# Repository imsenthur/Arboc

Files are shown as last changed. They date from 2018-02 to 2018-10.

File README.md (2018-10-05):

# Arboc
# Abstract:

Researches about underwater propulsion mainly illustrate the use of propellers or thrusters to propel a robot in an underwater environment whereas most of the aquatic animals change their body shape in order to navigate.The shape-change generating propulsion force makes them move forward or backward effectively.The underwater snake-like robot is a kind of bionic robot which changes its body shape to navigate in underwater environment.The aim of the project is to understand the dynamics of underwater robots in general and the effect of lift, drag and hydrodynamic coefficients on them and to simulate, validate and develop a snake-like robot which is robust enough to carry out underwater exploratory tasks.

# Scope of research ::

  •	Comprehensive simulation and validation of underwater bionic robots using ROS and gazebo.

  •	Goal based locomotion and object tracking for underwater exploratory robots using deep reinforcement learning.
  
# Team:

  • Aditya Singh [https://github.com/adityasingh3007]
  
  • Bhavya Krishna [https://github.com/BhavyaKrishna]
  
  • DC Vivek [https://github.com/dc28vivek]
  
  • Jack Samuel S [https://github.com/jaxxstar] 
  
  • Manu Aatitya [https://github.com/manuaatitya]  
  
  • Senthur Raj [https://github.com/imsenthur]
  
  • Vibashan VS [https://github.com/Vibashan]

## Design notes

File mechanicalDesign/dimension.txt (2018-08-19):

Head:
	Ixx=0.00021427111 kg*m2
	Iyy=0.00021427111 kg*m2
	Izz=0.000054 kg*m2
	rad=0.0335 m
	length=0.0765 m
	mass=0.095875 kg
Module:
	Ixx=0.0001378755 kg*m2
	Iyy=0.0001378755 kg*m2
	Izz=0.000052 kg*m2
	rad=0.0335 m
	length=0.06 m
	mass=0.093195 kg
Tail:
	Ixx=0.00064931795 kg*m2
	Iyy=0.00064931795 kg*m2
	Izz=0.000074 kg*m2
	rad=33.50mm
	length=118mm
	mass=0.13195 kg

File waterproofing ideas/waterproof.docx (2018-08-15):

Prebuilt waterproof:

Bang good waterproof servo = 972.43 (6.8k for 7)

Waterproofing manually (quite durable):

Method 1:

Materials reqd. :

Marine grease (730 Rs. For 7)

Plasti dip(900 Rs. For 7) (amazon)

Procedure:

Use marine grease on the top side of the servo where the gear is present, ehich does not allow water to flow from the top side of the servo.

Then use plasti dip to coat the servo with the plastic material which acts like a shrink tape when it dries and makes it really waterproof

During the plasti dip process we need to be careful to remove any air pockets near the edges during the drying phase and also make sure that the servo rotates in the drying phase

Once the plasti dip dries it looks like that there is an layer of plastic coat all over the servo which looks really sturdy

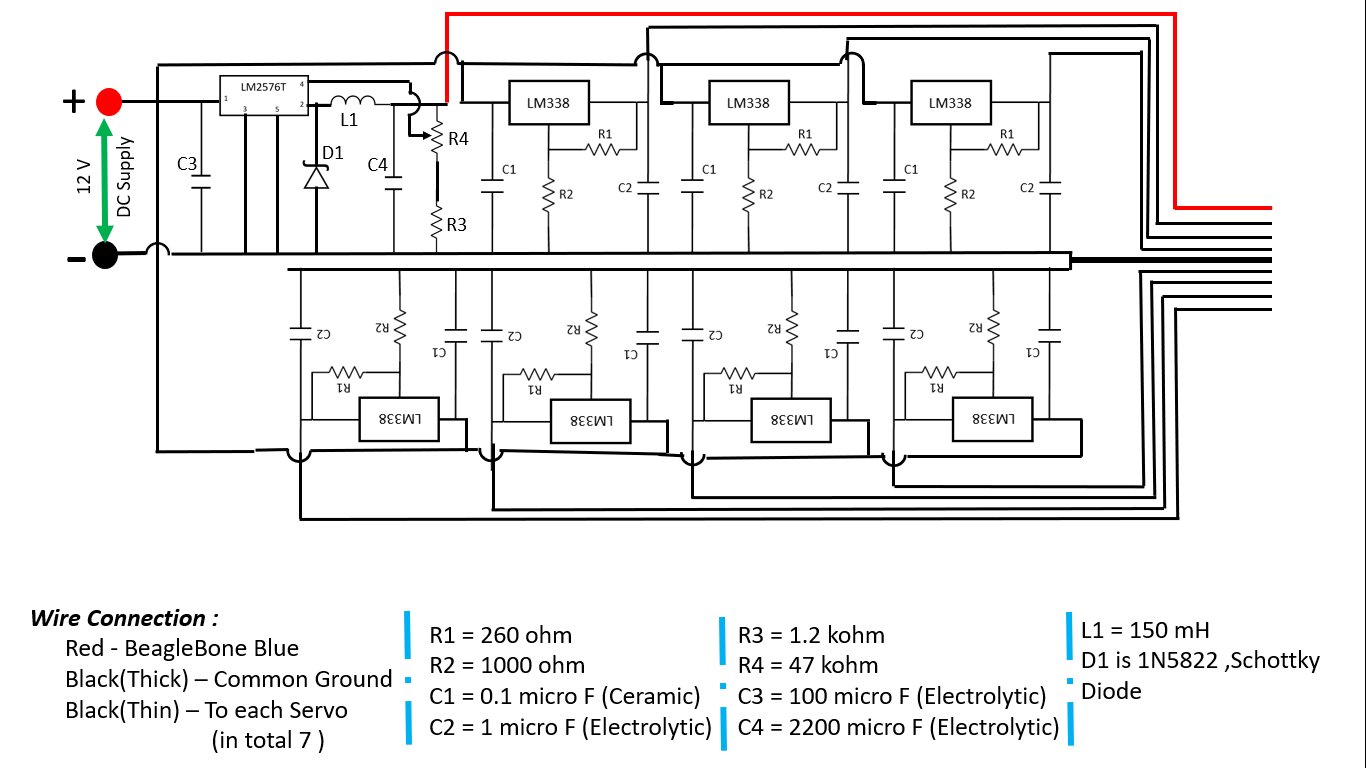
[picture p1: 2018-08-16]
powerSupplyDesign/circuit.png

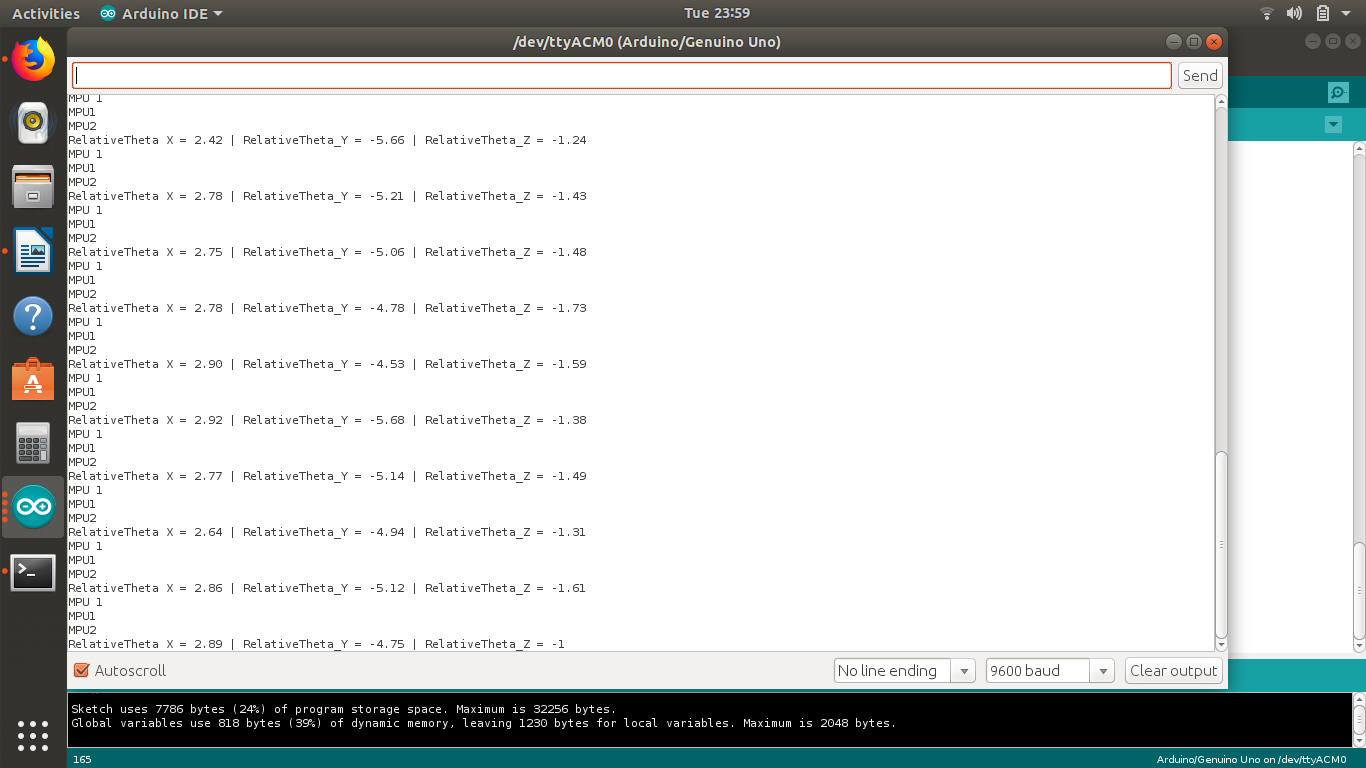
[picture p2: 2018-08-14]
control/IMU/Relative_angle.png

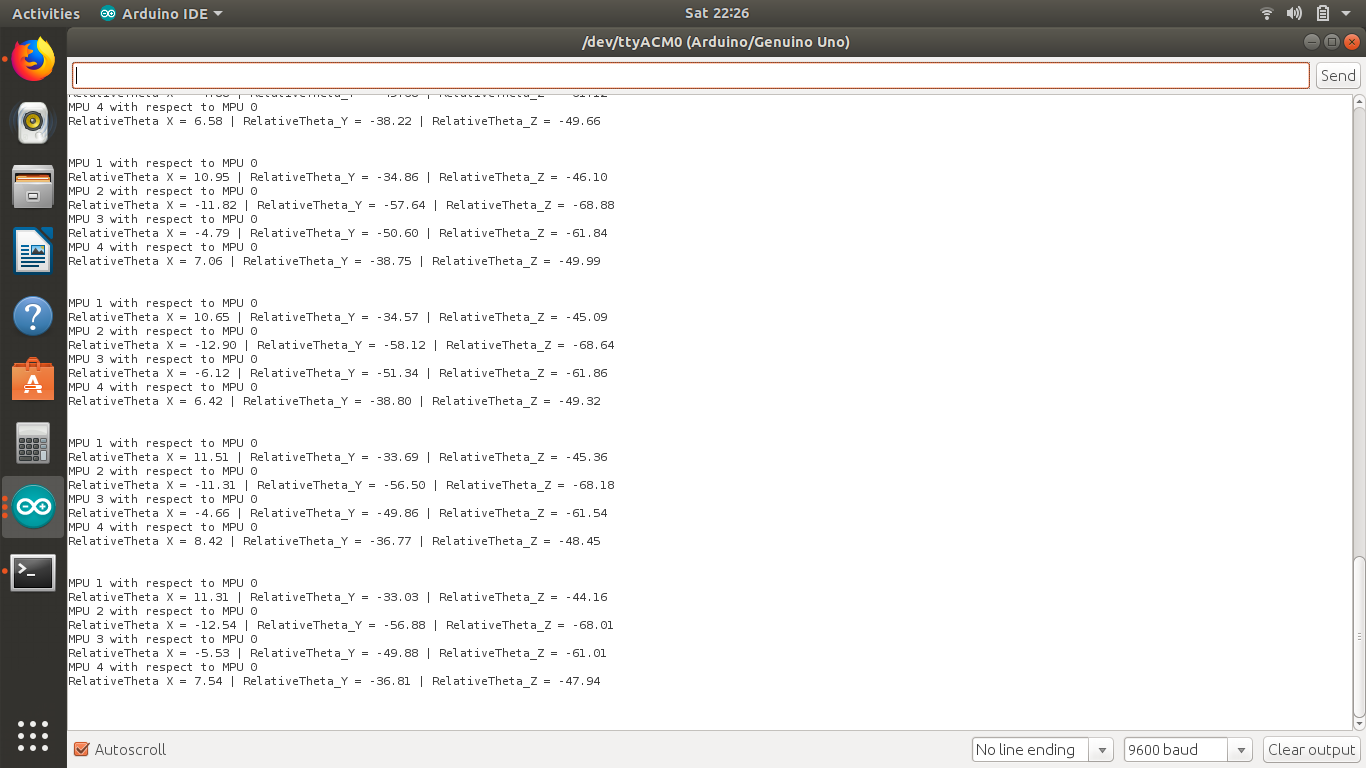
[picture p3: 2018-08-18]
control/IMU/relative_angle_5imu.png

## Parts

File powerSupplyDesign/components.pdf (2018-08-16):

LIST OF CIRCUIT ELEMENTS

S No. | Name | Range / Value | Qty
1. | LM338T Voltage Regulator (TO-220) | 1.2V to 32V, 5A | 10
2. | LM2576T Adj Regulator (TO-220) | | 03
3. | Resistor | 220 ohm,¼ watt 1 kohm,¼ watt 1.2 kohm,¼ watt | 10 10 03
4. | Rheostat | 47 kohm,¼ watt | 02
5. | Capacitor (Electrolytic) | 1 uF, 20 V 100 uF, 30 V 2200 uF, 20 V | 10 03 03
6. | Capacitor (Ceramic) | 0.1 uF, 30V | 10
7. | Inductor (CD74R) | 150 mH | 03
8. | Schottky Diode (1N5822) | 10-20V | 03
9. | Heat sinks | 1k/watt thermal resistance 30Watts disspation capacity | 10
10 | Thermal grease

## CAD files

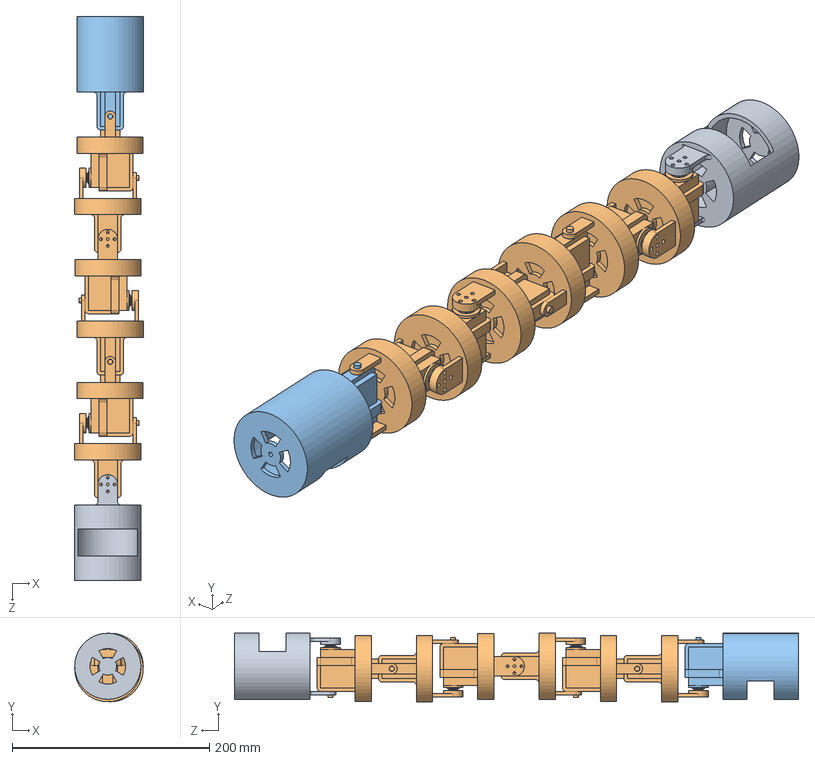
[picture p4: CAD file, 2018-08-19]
mechanicalDesign/solidworks/mainAssembly/arboc.SLDASM
69.5 x 69.5 x 571.3 mm
head
module x 6
tail

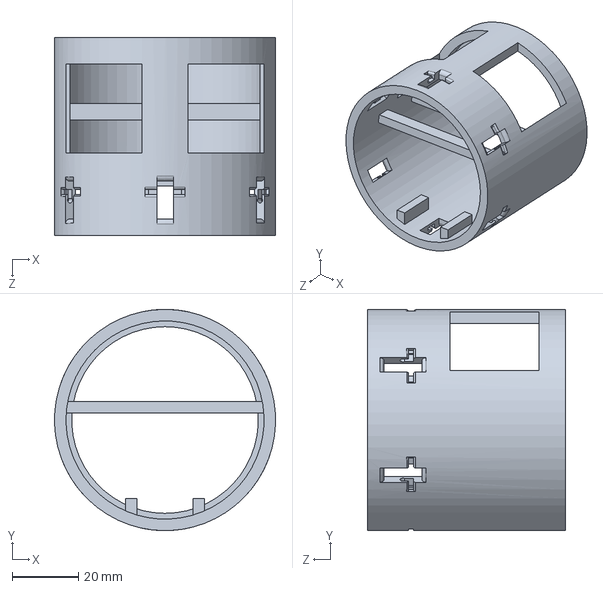
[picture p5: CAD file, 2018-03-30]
mechanicalDesign/solidworks/subAssembly/headNew.SLDASM
66.9 x 67.0 x 60.0 mm

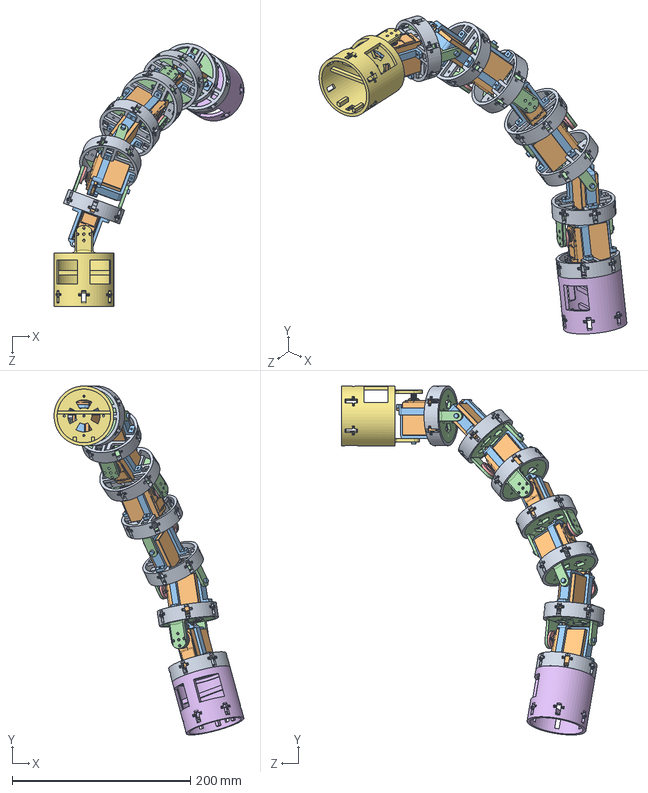
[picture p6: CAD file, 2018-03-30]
mechanicalDesign/solidworks/mainAssembly/arbocImprov.SLDASM
212.8 x 391.1 x 294.4 mm
LowerBracket x 7
Servo x 7
MiddleBracket x 7
UpperBracket x 6
Metalhorn x 6
Tail
Newhead

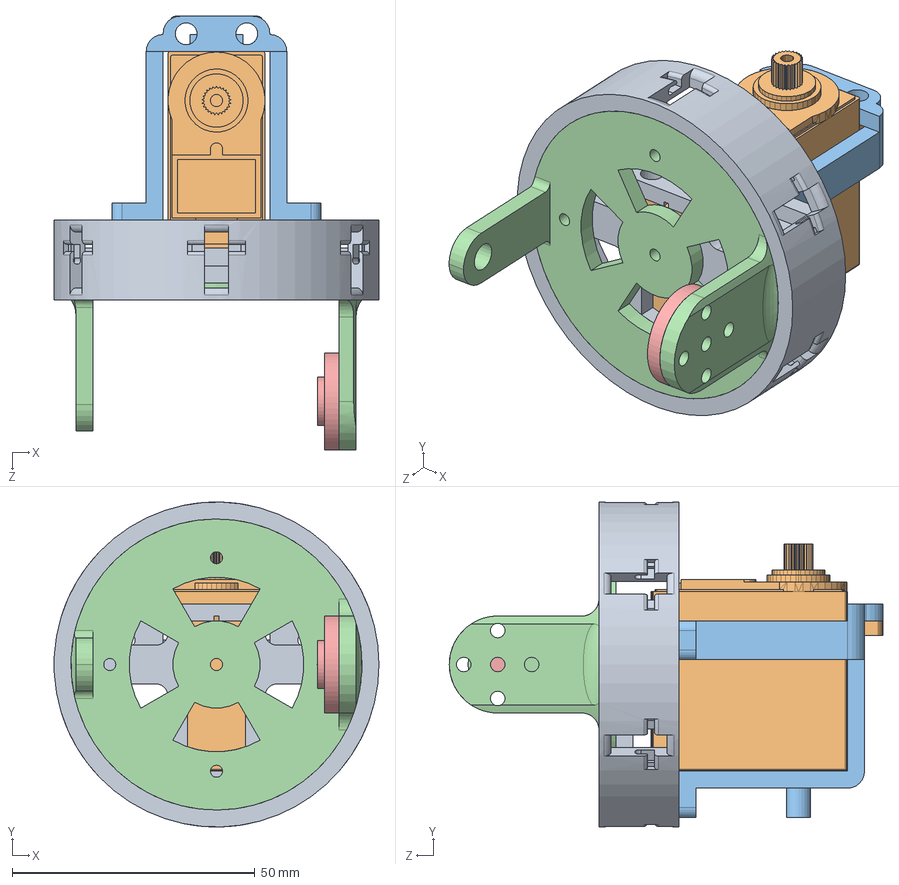
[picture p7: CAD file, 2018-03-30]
mechanicalDesign/solidworks/subAssembly/module.SLDASM
67.0 x 67.0 x 89.4 mm
LowerBracket
Servo
MiddleBracket
UpperBracket
Metalhorn

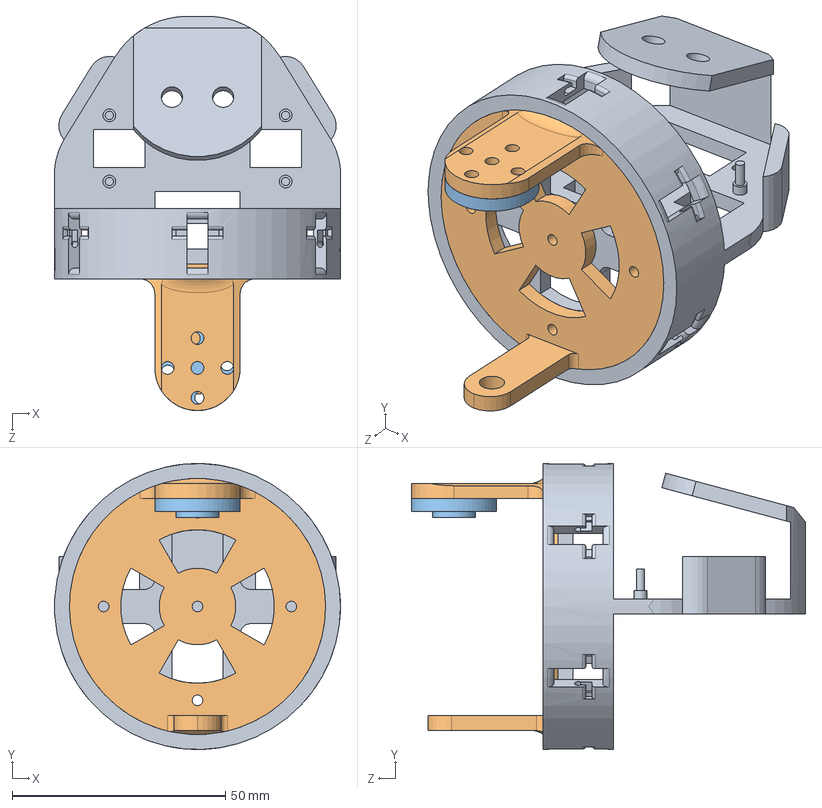
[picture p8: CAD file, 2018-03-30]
mechanicalDesign/solidworks/subAssembly/head.SLDASM
67.0 x 67.0 x 92.4 mm
Head
UpperBracket
Metalhorn

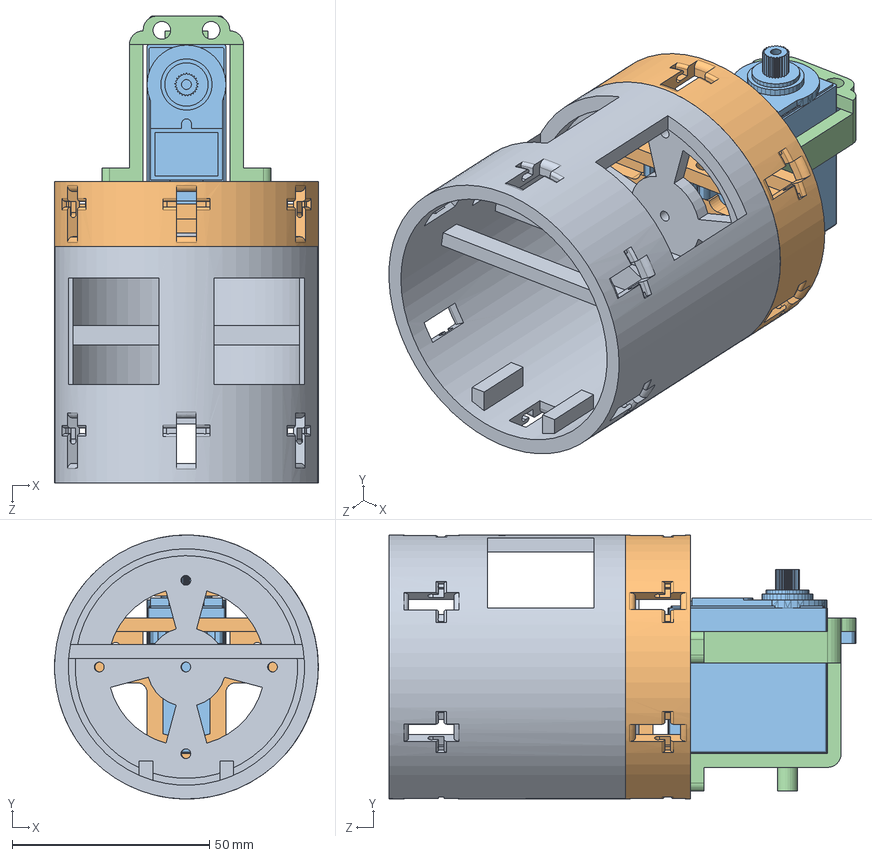
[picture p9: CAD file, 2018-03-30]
mechanicalDesign/solidworks/subAssembly/tail.SLDASM
67.0 x 67.0 x 118.5 mm
Tail
LowerBracket
Servo
MiddleBracket

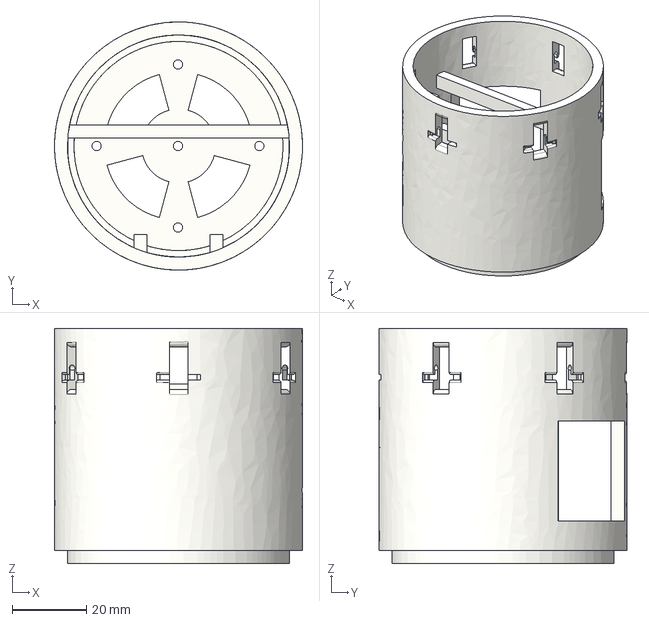
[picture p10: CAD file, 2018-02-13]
mechanicalDesign/3DprintedParts/type5.step
66.9 x 67.0 x 63.5 mm

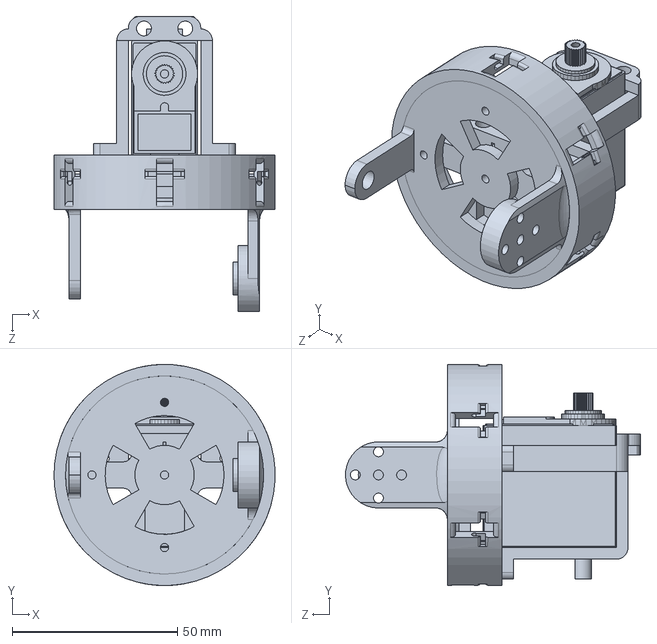
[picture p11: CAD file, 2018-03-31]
mechanicalDesign/solidworks/iges/link.SLDPRT
67.0 x 67.0 x 89.4 mm

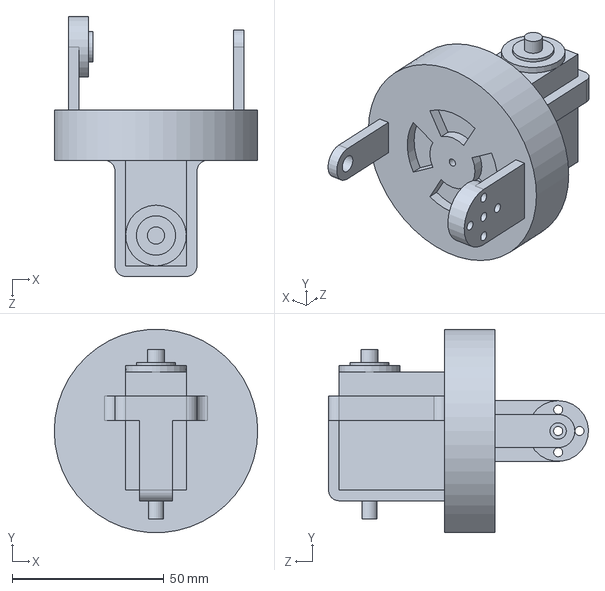
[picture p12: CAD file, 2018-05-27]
mechanicalDesign/solidworks/sldprt/module.SLDPRT
67.0 x 66.8 x 85.6 mm

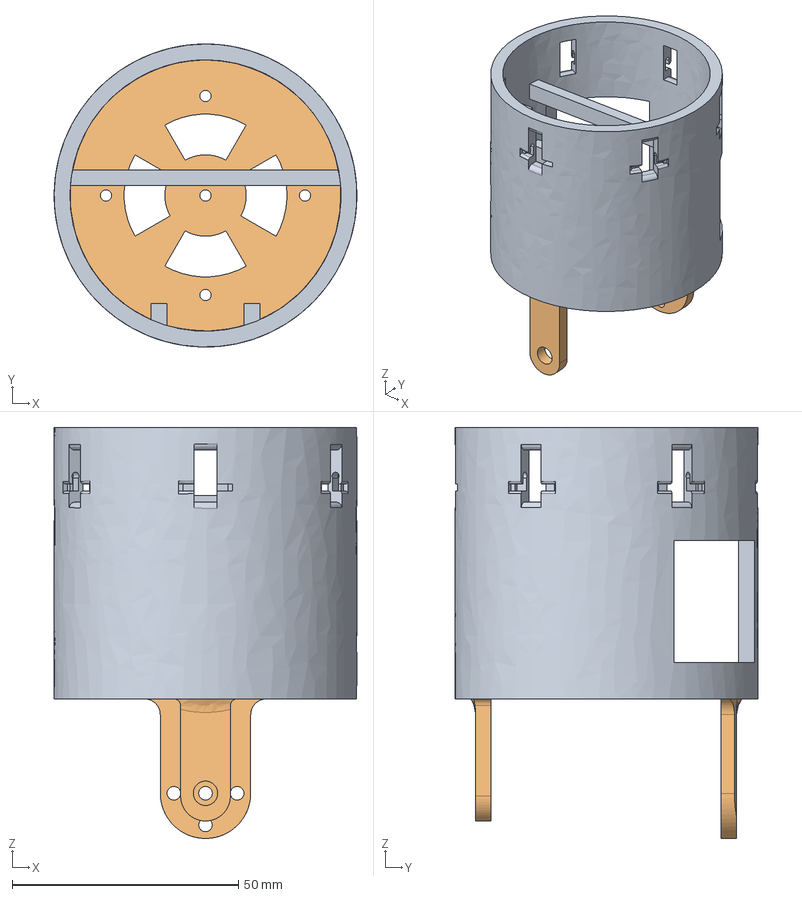
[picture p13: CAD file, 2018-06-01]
mechanicalDesign/solidworks/step/newHead.step
66.9 x 67.0 x 90.9 mm
Tail v1
UpperBracket v1

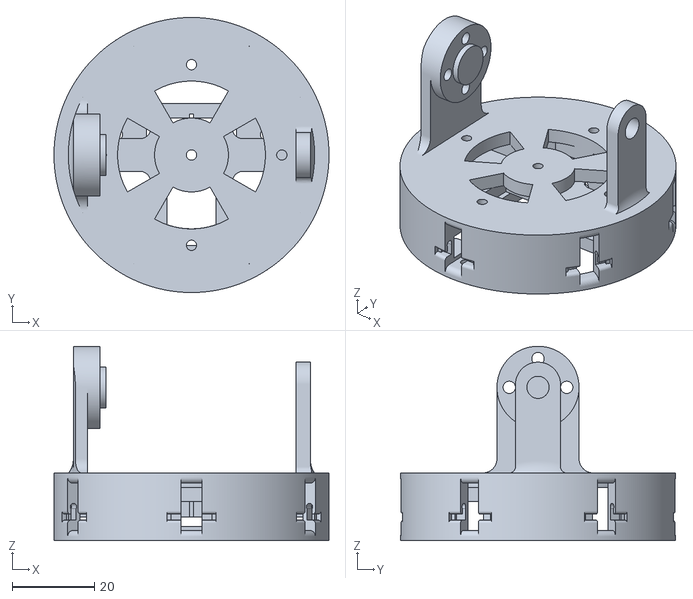
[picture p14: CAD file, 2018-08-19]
simulationExports/gazebo/stl/topModule.stl
67.0 x 67.0 x 47.4

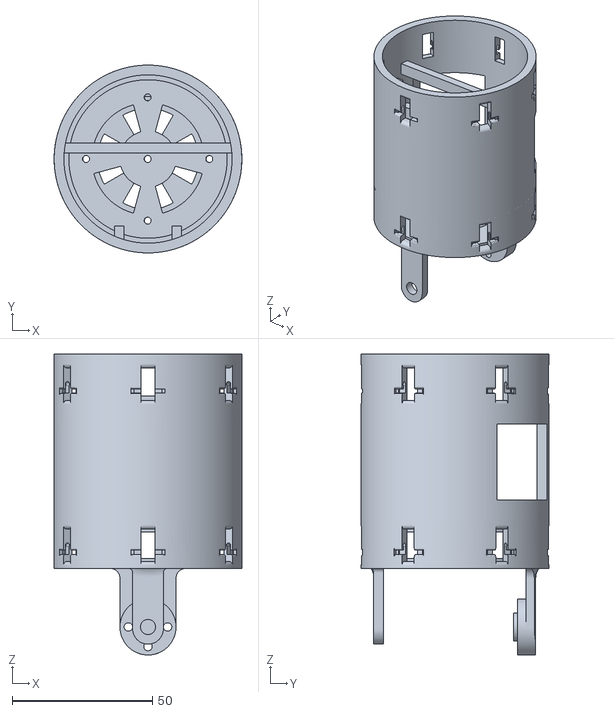
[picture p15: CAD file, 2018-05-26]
simulationExports/vrep/stl/headVisible.stl
67.0 x 67.0 x 107.4

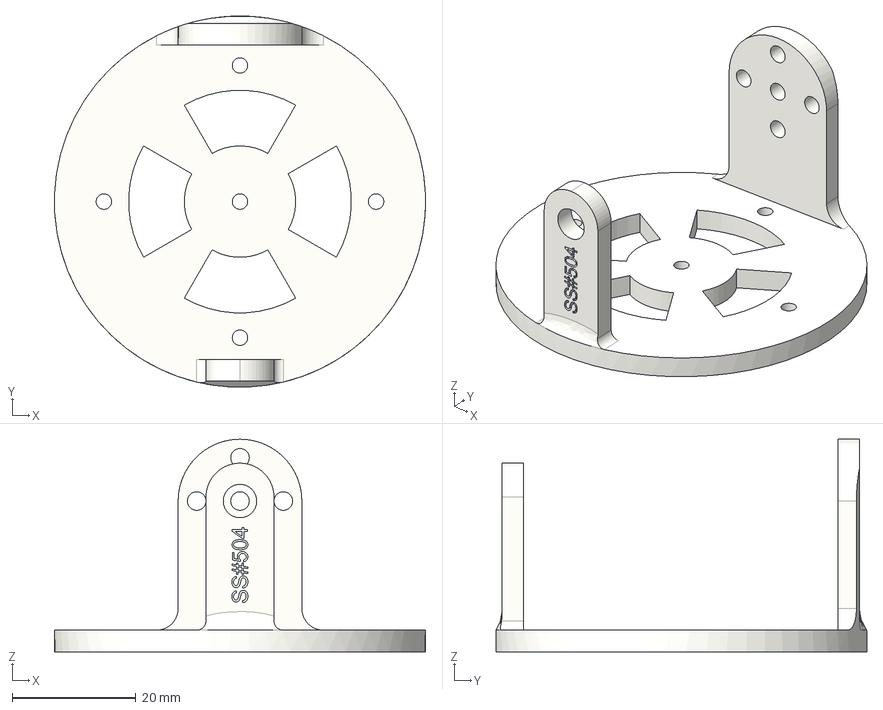
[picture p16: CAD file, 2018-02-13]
mechanicalDesign/3DprintedParts/type3.step
60.0 x 60.0 x 34.4 mm

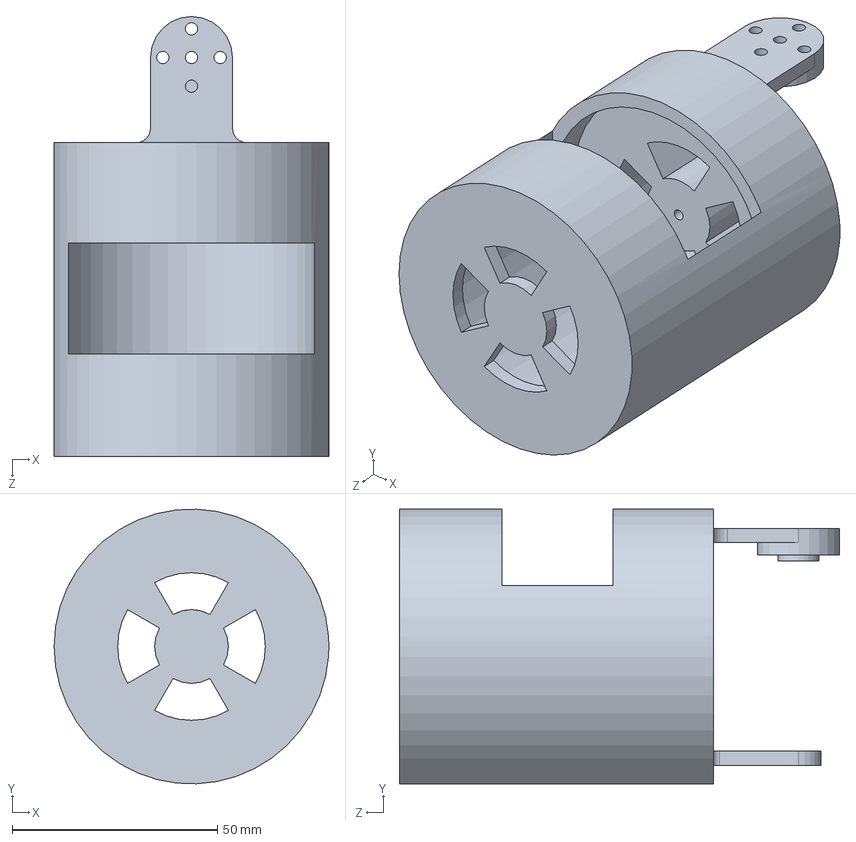
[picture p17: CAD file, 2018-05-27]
mechanicalDesign/solidworks/sldprt/head.SLDPRT
67.0 x 67.0 x 107.3 mm

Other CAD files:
mechanicalDesign/solidworks/iges/headLink.SLDPRT
mechanicalDesign/solidworks/step/metalHorn.step
simulationExports/gazebo/stl/moduleLeft.stl
simulationExports/vrep/stl/tailVisible.stl
mechanicalDesign/3DprintedParts/type1.step
mechanicalDesign/3DprintedParts/type1.stl
mechanicalDesign/3DprintedParts/type2.step
mechanicalDesign/3DprintedParts/type2.stl
mechanicalDesign/3DprintedParts/type3.stl
mechanicalDesign/3DprintedParts/type4.step
mechanicalDesign/3DprintedParts/type4.stl
mechanicalDesign/3DprintedParts/type5.stl
mechanicalDesign/3DprintedParts/type6.step
mechanicalDesign/3DprintedParts/type6.stl
mechanicalDesign/fusion360/NewDesignexport.f3d
mechanicalDesign/solidworks/iges/tailLink.SLDPRT
mechanicalDesign/solidworks/sldprt/headMod.SLDPRT
mechanicalDesign/solidworks/sldprt/headNew.SLDPRT
mechanicalDesign/solidworks/sldprt/lowerBracket.SLDPRT
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

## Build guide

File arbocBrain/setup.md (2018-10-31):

# arbocBrain

>  With an aim of tasking the robot with gait generation and goal based locomotion, we have buffed up a Beaglebone Blue with numerous packages that aid in both server-client communication and client-side computation.

## Installation

BeagleBone® Blue is an all-in-one Linux-based computer for robotics which comes preloaded with a Debian distribution (Debian jessie) which can be upgraded to a latest firmware from https://beagleboard.org/latest-images. Since most of the computation and processing is done with ROS on the server, it becomes crucial that the client has an active installation of ROS with all the necessary packages. Though ROS distros are available for Debian, its a bit finicky when it comes to installation and support. So we flashed the Beaglebone Blue with a custom ubuntu image (ubuntu 16.04) which we found at https://jh.app.box.com/v/530-707-Dropbox, which is a pre-built image courtesy of Robert Nelson, Jeff O’Brian, and louis whitcomb that comes with ROS Kinetic pre-installed. The entire process has been explained further with much detail below.

#### Expanding file system partition:
The image mentioned above is a 8GB ubuntu-16.04 image which converts the attached SD card to a file system of 8GB capacity irrespective of its native capacity. Make sure to expand the file system partition before proceeding further.

Refer to https://dev.iachieved.it/iachievedit/expanding-your-beaglebone-microsd-filesystem/.

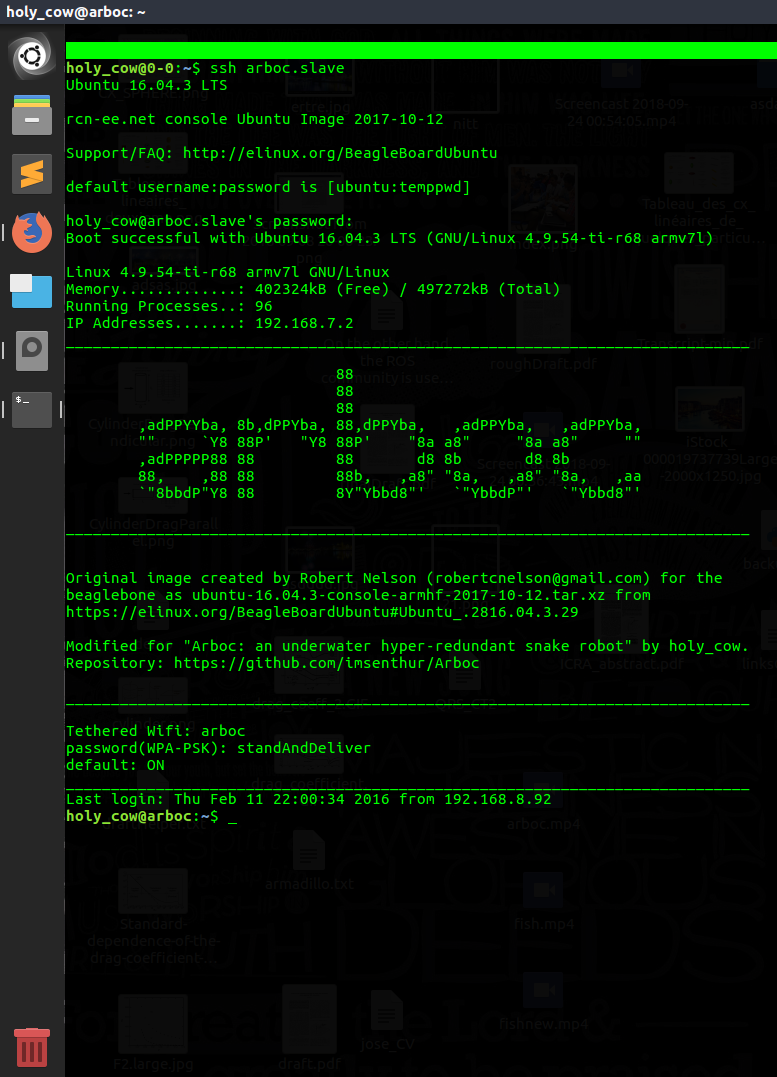
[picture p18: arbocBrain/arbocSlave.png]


#### ROS network configuration requirements:
ROS has certain requirements for the network configuration:

- There must be complete, bi-directional connectivity between all pairs of machines, on all ports. 
- Each machine must advertise itself by a name that all other machines can resolve. 

To check basic connectivity, ping each machine from itself,
```html
  ~ssh arboc.slave
  ~ping arboc.slave
```
and also ping between machines,
```html
  ~ssh arboc.slave
  ~ping arboc.master
```
you should see something like this,
```html
  PING arboc.master: 56 data bytes
  64 bytes from 192.168.1.1: icmp_seq=0 ttl=63 time=1.868 ms
  64 bytes from 192.168.1.1: icmp_seq=1 ttl=63 time=2.677 ms
  64 bytes from 192.168.1.1: icmp_seq=2 ttl=63 time=1.659 ms
```
#### ROS network setup:
Set your ROS environment variables on both master (server) and the slave (client). You can perform this by editing your bashrc script to include "ROS_MASTER_URI" and "ROS_HOSTNAME" which are crucial when it comes to networking with ROS.
```html
  ~sudo subl ~/.bashrc
```
and add these lines to the end of script,
```html
  export ROS_MASTER_URI=http://arboc.master:11311
  export ROS_HOSTNAME=arboc.master
```
and source it.
```html
  ~source ~/.bashrc
```
Make sure you perform the above mentioned steps on the Beaglebone too (but with ROS_HOSTNAME=arboc.slave).
Here "arboc.master" and "arboc.slave" corresponds to the IP address of the master(PC/server) and slave(Beaglebone Blue) respectively. You can add these entries to your "/etc/hosts" to save the hassle of typing the entire IP address everytime you login into your device and it also enables multiple devices to identify each other. The hosts file tells each device how to convert specific names into an IP address.

Once the environment variables are set you must be able to get the following output, 
For the master (PC/server),
```html
  ~echo $ROS_MASTER_URI
  http://arboc.master:11311
  ~echo $ROS_HOSTNAME
  arboc.master
```
and for the slave (Beaglebone Blue),

```html
  ~echo $ROS_MASTER_URI
  http://arboc.master:11311
  ~echo $ROS_HOSTNAME
  arboc.slave
```
We are assuming that "roscore" is being run only on the master and the slave subscribes to multiple topics that are being published. 

#### Time synchronization:
You may have a discrepancy in system times between the master and slave. You can check it from the slave(Beaglebone Blue) using,
```html
  ~ssh arboc.slave
  ~ntpdate -q arboc.master
```
If there is a discrepancy, install chrony and ntpdate by running,
```html
  sudo apt-get install chrony ntpdate
```
Once the installation is successful, make sure you disable "automatic time update" so that the system time doesnot get changed during execution. In order to do disable it, run the following command,
```html
  timedatectl set-ntp false
```
Then configure chrony to query the server's system time, and slowly get the time in-sync. In order to do that, just open the file "/etc/chrony/chrony.conf" in your text editor and add these lines to it,
```html
  server arboc.master minpoll 0 maxpoll 5 maxdelay .05
```
Finally, make sure that the timezones between the master and slave are consistent. If they're not the same then you can change it using,
```html
  sudo timedatectl set-timezone Asia/Kolkata
```
Note that the above command changes the timezone to IST(Indian Standard Time).

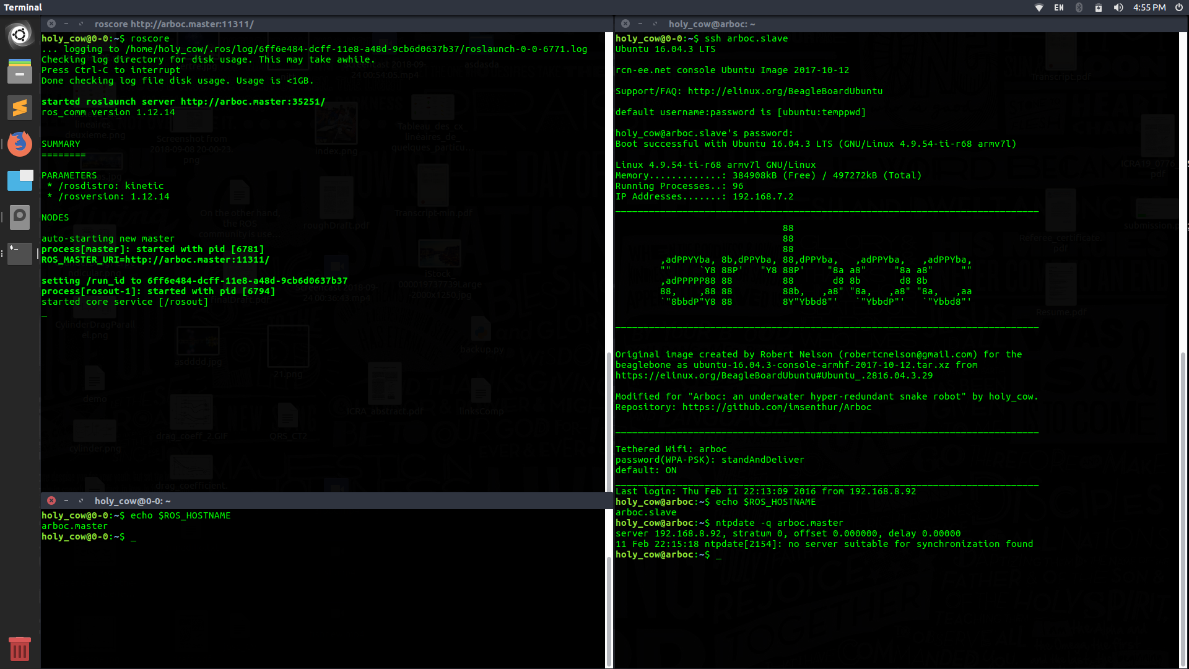
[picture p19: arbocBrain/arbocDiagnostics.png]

#### Diagnostics:
To start with, query the current time offset by running,
```html
  ~ssh arboc.slave
  ~sudo ntpdate -q arboc.master
```
If they are at perfect sync, you're good to go.
Start the roscore on master (PC/server) and run a publisher node,
```html
  ~roscore
  ~rostopic pub -r 10 /hello std_msgs/String "Hello"
```
Now ssh onto your slave and list the topics being published,
```html
  ~ssh arboc.slave
  ~rostopic list
```
You must be able to see a list of all the topics that are being published,
```html
  /hello
  /rosout
  ...
```
Now try echoing the published topic,
```html
  ~rostopic echo /hello
```
you should be getting "hello"s on the output terminal at a rate of 10Hz.
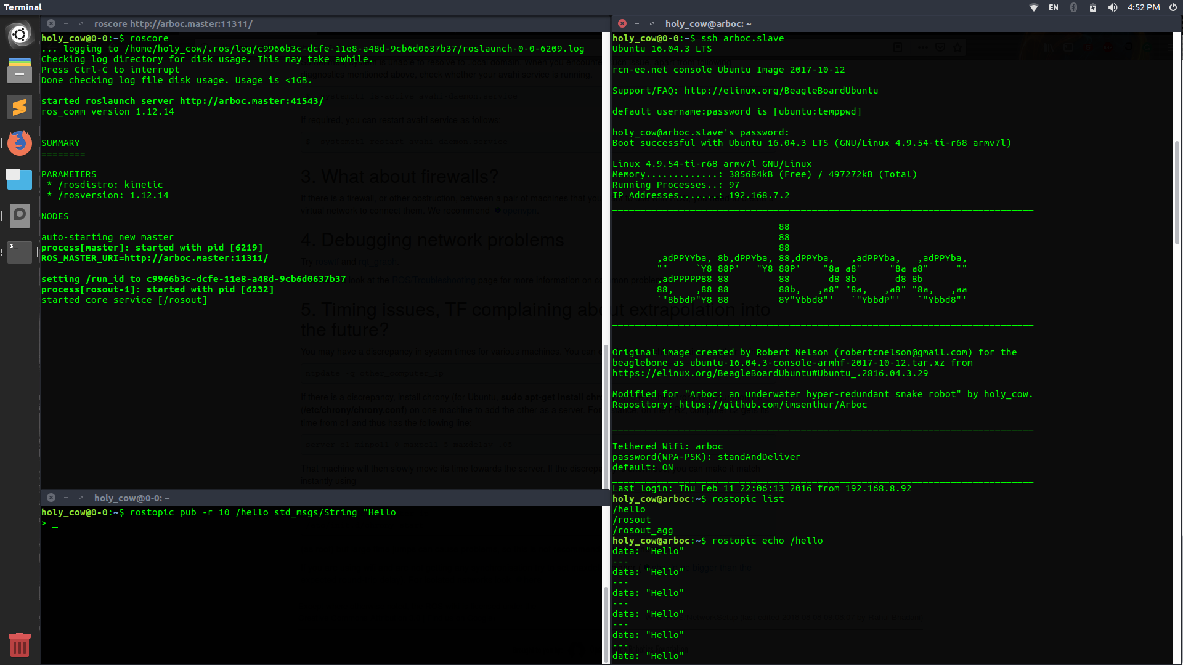
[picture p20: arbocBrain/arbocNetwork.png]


[Back To The Top](#arbocBrain)

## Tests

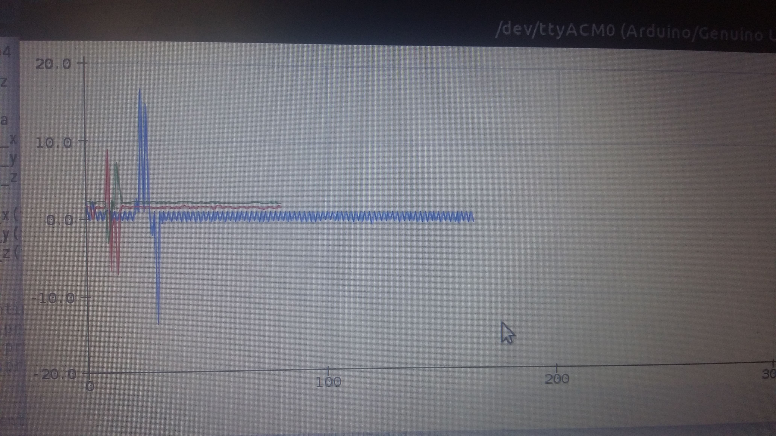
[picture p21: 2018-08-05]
control/IMU/complimentary_result.jpg

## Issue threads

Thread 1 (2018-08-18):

Adding more than 5 IMUs to the I2C mux

BhavyaKrishna, 2018-08-18:
Considering our project need 7 IMU's to be connected, there are two things you can try
(i) Change the address of 2 MPU's to 0x69 and connect them to the any of the working channels, say SD0-SC0 and SD1-SC1 and read from those channels by using address 0x69.
(ii) Check if the problem is in the 6th channels of the I2C MUX by using the 7th and 8th channels with the first 5 channels transmitting data

All this is suggested because you said you are currently not able to read 6 IMU's at the same time

manuaatitya, 2018-08-19:
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

Thanks for the suggestions :+1:
i) Changing the address of the imu worked
ii) The problem was with the 5th port in the i2c multiplexer , when i connect the imu to the 6th or 7th ports and get 6 readings it works fine even without changing the address.

The issue is solved but if i print values individually using only 1 imu connected to the ports the 5th port gives correct readings so ultimately the main problem is solved but i cant figure out why it is happening so.

I even tried using pullup resistors to the clock line and data line of the multiplexer even though the imu breakout boards have one but still no improvement in the results.

Welcoming logical suggestions to this issue.

Closed 2018-08-19.

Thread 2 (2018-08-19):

Relative angle between subsequent links.

imsenthur, 2018-08-19:
https://github.com/imsenthur/Arboc/blob/f7e5cf4321e8ad16fa542bdcef1aca63ad1ba184/IMU_Arboc/imu_multiplexer/imu_multiplexer.ino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

@manuaatitya The feedback looks excellent but the code committed computes the relative angle between the current link and the head [Link_01] however the control loop requires relative angle between subsequent links. Do look into it and make the necessary changes. :)

manuaatitya, 2018-08-20:
@imsenthur  Thanks for pointing out the bug.
Corrected the code to compute relative angle between subsequent links and have also set the update rate of the imu to 50hz.

manuaatitya, 2018-08-20:
Issue resolved.
Closing the issue.

Closed 2018-08-20.

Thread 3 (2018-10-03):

Function missing modularity

imsenthur, 2018-10-03:
@jaxxstar Try making the PID function modular with arguments (_Kp, Ki, Kd_) and ( _jointAngles_).

https://github.com/imsenthur/Arboc/blob/8568311be7e7226d4689cfcb32861fddfd65f343/control/Closed%20Loop/PD_Implementation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

Closed 2023-01-05.

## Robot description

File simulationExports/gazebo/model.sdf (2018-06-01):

<?xml version="1.0"?>
<sdf version="1.5">
	<model name="snake">
		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
		<link name="base_link">
			<pose>0 0 0.03825 0 0 0</pose>
			<inertial>
				<mass>0.095875</mass>
				<inertia>
					<ixx>0.00021427111</ixx>
					<iyy>0.00021427111</iyy>
					<izz>0.000054</izz>
					<ixy>0</ixy>
					<ixz>0</ixz>
					<iyz>0</iyz>
				</inertia>
			</inertial>
			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
		</link>

		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
		<link name="link_1">
			<pose>0 0 0.1115 0 0 0</pose>
			<inertial>
				<mass>0.093195</mass>
				<inertia>
					<ixx>0.0001378755</ixx>
					<iyy>0.0001378755</iyy>
					<izz>0.000052</izz>
					<ixy>0</ixy>
					<ixz>0</ixz>
					<iyz>0</iyz>
				</inertia>
			</inertial>
			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
		</link>

		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
		<joint type="revolute" name="revolute_1">
			<pose>0 0 -0.0145 0 0 0</pose>
			<parent>base_link</parent>
			<child>link_1</child>
			<axis>
				<xyz>0 1 0</xyz>
				<limit>
					<lower>-1.309</lower>
					<upper>1.309</upper>
				</limit>
			</axis>
		</joint>

		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
		<link name="link_2">
			<pose>0 0 0.1735 0 0 0</pose>
			<inertial>
				<mass>0.093195</mass>
				<inertia>
					<ixx>0.0001378755</ixx>
					<iyy>0.0001378755</iyy>
					<izz>0.000052</izz>
					<ixy>0</ixy>
					<ixz>0</ixz>
					<iyz>0</iyz>
				</inertia>
			</inertial>
			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
		</link>

		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
		<joint type="revolute" name="revolute_2">
			<pose>0 0 -0.0145 0 0 0</pose>
			<parent>link_1</parent>
			<child>link_2</child>
			<axis>
				<xyz>1 0 0</xyz>
				<limit>
					<lower>-1.309</lower>
					<upper>1.309</upper>
				</limit>
			</axis>
		</joint>

		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
		<link name="link_3">
			<pose>0 0 0.2355 0 0 0</pose>
			<inertial>
				<mass>0.093195</mass>
				<inertia>
					<ixx>0.0001378755</ixx>
					<iyy>0.0001378755</iyy>
					<izz>0.000052</izz>
					<ixy>0</ixy>
					<ixz>0</ixz>
					<iyz>0</iyz>
				</inertia>
			</inertial>
			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
		</link>

		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
		<joint type="revolute" name="revolute_3">
			<pose>0 0 -0.0145 0 0 0</pose>
			<parent>link_2</parent>
			<child>link_3</child>
			<axis>
				<xyz>0 1 0</xyz>
				<limit>
					<lower>-1.309</lower>
					<upper>1.309</upper>
				</limit>
			</axis>
		</joint>

		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
		<link name="link_4">
			<pose>0 0 0.2975 0 0 0</pose>
			<inertial>
				<mass>0.093195</mass>
				<inertia>
					<ixx>0.0001378755</ixx>
					<iyy>0.0001378755</iyy>
					<izz>0.000052</izz>
					<ixy>0</ixy>
					<ixz>0</ixz>
					<iyz>0</iyz>
				</inertia>
			</inertial>
			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
		</link>

		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
		<joint type="revolute" name="revolute_4">
			<pose>0 0 -0.0145 0 0 0</pose>
			<parent>link_3</parent>
			<child>link_4</child>
			<axis>
				<xyz>1 0 0</xyz>
				<limit>
					<lower>-1.309</lower>
					<upper>1.309</upper>
				</limit>
			</axis>
		</joint>

		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
		<link name="link_5">
			<pose>0 0 0.3595 0 0 0</pose>
			<inertial>
				<mass>0.093195</mass>
				<inertia>
					<ixx>0.0001378755</ixx>
					<iyy>0.0001378755</iyy>
					<izz>0.000052</izz>
					<ixy>0</ixy>
					<ixz>0</ixz>
					<iyz>0</iyz>
				</inertia>
			</inertial>
			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
		</link>

		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
		<joint type="revolute" name="revolute_5">
			<pose>0 0 -0.0145 0 0 0</pose>
			<parent>link_4</parent>
			<child>link_5</child>
			<axis>
				<xyz>0 1 0</xyz>
				<limit>
					<lower>-1.309</lower>
					<upper>1.309</upper>
				</limit>
			</axis>
		</joint>

		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
		<link name="link_6">
			<pose>0 0 0.4215 0 0 0</pose>
			<inertial>
				<mass>0.093195</mass>
				<inertia>
					<ixx>0.0001378755</ixx>
					<iyy>0.0001378755</iyy>
					<izz>0.000052</izz>
					<ixy>0</ixy>
					<ixz>0</ixz>
					<iyz>0</iyz>
				</inertia>
			</inertial>
			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
		</link>

		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
		<joint type="revolute" name="revolute_6">
			<pose>0 0 -0.0145 0 0 0</pose>
			<parent>link_5</parent>
			<child>link_6</child>
			<axis>
				<xyz>1 0 0</xyz>
				<limit>
					<lower>-1.309</lower>
					<upper>1.309</upper>
				</limit>
			</axis>
		</joint>

		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
		<link name="tail_link">
			<pose>0 0 0.51325 0 0 0</pose>
			<inertial>
				<mass>0.093195</mass>
				<inertia>
					<ixx>0.0001378755</ixx>
					<iyy>0.0001378755</iyy>
					<izz>0.000052</izz>
					<ixy>0</ixy>
					<ixz>0</ixz>
					<iyz>0</iyz>
				</inertia>
			</inertial>
			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
		</link>

		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
		<joint type="revolute" name="tail_revolute">
			<pose>0 0 -0.04375 0 0 0</pose>
			<parent>link_6</parent>
			<child>tail_link</child>
			<axis>
				<xyz>0 1 0</xyz>
				<limit>
					<lower>-1.309</lower>
					<upper>1.309</upper>
				</limit>
			</axis>
		</joint>
	</model>
</sdf>

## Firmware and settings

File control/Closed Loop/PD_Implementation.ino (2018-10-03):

#include <Servo.h>

# define Number_of_IMU 6
#define Number_of_SERVO (Number_of_IMU-1)

int desired_angle[Number_of_IMU];
int theta[Number_of_IMU];

//Setting up Servo Instances
Servo servo1;
Servo servo2;
Servo servo3;
Servo servo4;
Servo servo5;
Servo servo6;  

void write_angle()                          //For assigning the values of desired angle and passing it to the PID controller
{
  for(int k=0;k<Number_of_SERVO;k++)
  {
    desired_angle[k]=15;                      //Here we'll have to give the snake equation function
  }
  PD_inner();
}

void PD_inner()   //Passing the desired angles to the function
{             
  int kp= 0.9,kd= 1.3,PID;
  int error,previous_error,difference_error;
  
      error=0;
      while(error>5)
      {
        previous_error  = error;
        error = (desired_angle[0]-theta[1]);          //Theta is the angle given by the IMU
        difference_error  = error-previous_error;
        PID = (kp*error)  + (kd*difference_error);
        servo1.write(desired_angle[0]+PID);        
      }
      error=0;
      while(error>5)
      {
        previous_error  = error;
        error = (desired_angle[1]-theta[2]);          //Theta is the angle given by the IMU
        difference_error  = error-previous_error;
        PID = (kp*error)  + (kd*difference_error);
        servo2.write(desired_angle[1]+PID);        
      }      
      error=0;
      while(error>5)
      {
        previous_error  = error;
        error = (desired_angle[2]-theta[3]);          //Theta is the angle given by the IMU
        difference_error  = error-previous_error;
        PID = (kp*error)  + (kd*difference_error);
        servo3.write(desired_angle[2]+PID);        
      }      
      error=0;
      while(error>5)
      {
        previous_error  = error;
        error = (desired_angle[3]-theta[4]);          //Theta is the angle given by the IMU
        difference_error  = error-previous_error;
        PID = (kp*error)  + (kd*difference_error);
        servo4.write(desired_angle[3]+PID);        
      }
      error=0;
      while(error>5)
      {
        previous_error  = error;
        error = (desired_angle[4]-theta[5]);          //Theta is the angle given by the IMU
        difference_error  = error-previous_error;
        PID = (kp*error)  + (kd*difference_error);
        servo5.write(desired_angle[4]+PID);        
      }
            error=0;
      while(error>5)
      {
        previous_error  = error;
        error = (desired_angle[5]-theta[6]);          //Theta is the angle given by the IMU
        difference_error  = error-previous_error;
        PID = (kp*error)  + (kd*difference_error);
        servo6.write(desired_angle[5]+PID);        
      }
  
}

void setup() 
{
  servo1.attach(3);
  servo2.attach(10);
  servo3.attach(9);
  servo4.attach(5);
  servo5.attach(2);
  servo6.attach(8);
  
//Put snake in starting position
   servo1.write(90);
   servo2.write(90);
   servo3.write(90);
   servo4.write(90);
   servo5.write(90);
   servo6.write(90-13); 
   
}

void loop()
{  
  write_angle();
}

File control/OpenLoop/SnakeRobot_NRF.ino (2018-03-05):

#include <Servo.h>
#include <SPI.h>
#include <nRF24L01.h>
#include <RF24.h>
#include<stdio.h>
#include <avr/io.h>
#include <util/delay.h>
#include <stdlib.h>
#include<avr/interrupt.h>

// function to initialize UART
void uart_init (void)
{
    UBRR0=207;  //Baud Rate 9600
  UCSR0B|=(1<<RXCIE0)|(1<<RXEN0)|(1<<TXEN0);  //Enabling Recieve Interrupt enable,Transmitter and Reciever
}

void uart_transmit (unsigned char data)
{
    while (!( UCSR0A & (1<<UDRE0)));                // wait while register is free
    UDR0 = data;                                   // load data in the register
}

/*
 * Serpentine lateral plane:
 * a=0.6*pi
 * b=2*pi
 * c=0
 * 
 *  a=0.75*pi;
    b=3.5*pi;
    c=-0.2*pi;
    num_segments = 5;

          a=1.5*pi;
          b=3*pi;
          c=0*pi;


    
 */

 /*
  * Rolling gait:
  * a=0.9*pi
  * b=1*pi
  * c=0
  * n=8
  * phase diff += 0.1
  * add pi to switch direction
  */
 
// Define servo objects for the snake segments
Servo s1; 
Servo s2;
Servo s3;
Servo s4; 
Servo s5;
Servo s6;
Servo s7;
int gait=1;
int direc=2;
const float pi = 3.141593;
int counter = 0; 
int frequency = 1; 
int startPause = 2000; 
int data[2];
int flag=0;

char tx='1';

float a = 0.9*pi;                                   //Ampli Coeff
float b = 1*pi;                                     //Curve Coeff      
float c = 0;                                        //Turn Coeff
float num_segments = 8;
float gamma=-c/num_segments;
float beta=b/num_segments;
float alpha=a*abs(sin(beta/2));
unsigned long previousMillis = 0;
long interval = 4;

RF24 radio(6, 7); // CE, CSN
const byte address[6] = "00001";

void setup() 
{
  uart_init();
  Serial.begin(9600);
  radio.begin();
  radio.openReadingPipe(0, address);
  radio.setPALevel(RF24_PA_MIN);
  radio.startListening();

  // Attach segments to pins  
   s1.attach(3); //blue left - 1st servo
   s2.attach(10); //black right - 2nd servo
   s3.attach(9); //violet right - 3rd servo 
   s4.attach(5); //black left - 4th servo 
   s5.attach(2); //white left - 5th servo 
   s6.attach(8); //blue right - 6th servo 
   s7.attach(4); //brown left - 7th servo 
 
//Put snake in starting position
   s1.write(90);
   s2.write(90);
   s3.write(90);
   s4.write(90);
   s5.write(90);
   s6.write(90-13); 
   s7.write(90-7); 
   delay(startPause);
   previousMillis = millis();
}
void loop() 
{
  if (radio.available())
  {
    //Serial.println("YEAH");
    radio.read(&data, sizeof(data));
    direc =data[0];
    gait =data[1];
    Serial.println(gait);
    Serial.println(direc);
  } 
  if(gait==3 && flag ==0)
  {
    flag =1;
    Serial.println("The gait is:");
    Serial.println(gait);
    Serial.println("direction:");
    Serial.println(direc);

    //Helical gait
         if(direc ==2)
        {
          a=0.8*pi;
          b=2*pi;
          c=0;
          num_segments = 8;
          gamma=-c/num_segments;
          beta=b/num_segments;
          alpha=a*abs(sin(beta/2));
          //Serial.println("helical");
          for(counter = 0; counter < 360;) 
          {
            unsigned long currentMillis = millis();
            if (currentMillis - previousMillis >= interval)
            {
              previousMillis = currentMillis;
              s1.write(90 + (alpha*sin(frequency*counter*pi/180+0*beta)+gamma)*180/pi);
              //Serial.println((alpha*sin(frequency*counter*pi/180+0*beta)+gamma)*180/pi);
              s2.write(90 + (alpha*sin(frequency*counter*pi/180+1*beta+pi/2)+gamma)*180/pi);
              s3.write(90 + (alpha*sin(frequency*counter*pi/180+2*beta)+gamma)*180/pi);
              s4.write(90 + (alpha*sin(frequency*counter*pi/180+3*beta+pi/2)+gamma)*180/pi);
              s5.write(90 + (alpha*sin(frequency*counter*pi/180+4*beta)+gamma)*180/pi);
              s6.write(90 - 13 + (alpha*sin(frequency*counter*pi/180+5*beta+pi/2)+gamma)*180/pi);
              s7.write(90 - 7 + (alpha*sin(frequency*counter*pi/180+6*beta)+gamma)*180/pi);
              counter += 1;
            }       
          }
        }
    flag =0;
  }
  else if(gait==2 && flag ==0)
  {
    flag =1;
    Serial.println("The gait is:");
    Serial.println(gait);
    Serial.println("direction:");
    Serial.println(direc);

    //Rolling gait
          if(direc ==2 || direc == 4)
        {
          //Roll right
          a=0.9*pi;
          b=1.0*pi;
          c=0;
          num_segments = 8;
          gamma=-c/num_segments;
          beta=b/num_segments;
          alpha=a*abs(sin(beta/2));
          for(counter = 0; counter < 360;) 
          {
            unsigned long currentMillis = millis();
            if (currentMillis - previousMillis >= interval);
            {
              previousMillis = currentMillis;
              s1.write(90 + (alpha*sin(frequency*counter*pi/180+0*beta)+gamma)*180/pi);
              s2.write(90 + (alpha*sin(frequency*counter*pi/180+0.1*beta+pi/2)+gamma)*180/pi);
              s3.write(90 + (alpha*sin(frequency*counter*pi/180+0.2*beta)+gamma)*180/pi);
              s4.write(90 + (alpha*sin(frequency*counter*pi/180+0.3*beta+pi/2)+gamma)*180/pi);
              s5.write(90 + (alpha*sin(frequency*counter*pi/180+0.4*beta)+gamma)*180/pi);
              s6.write(90 - 13 + (alpha*sin(frequency*counter*pi/180+0.5*beta+pi/2)+gamma)*180/pi);
              s7.write(90 - 7 + (alpha*sin(frequency*counter*pi/180+0.6*beta)+gamma)*180/pi);
              counter += 1;
            }       
          }
        }
         else if(direc == 0 || direc == 6)
        {
          //Roll left
          a=0.9*pi;
          b=1*pi;
          c=0;
          num_segments = 8;
          gamma=-c/num_segments;
          beta=b/num_segments;
          alpha=a*abs(sin(beta/2));
          for(counter = 0; counter < 360;) 
          {
            unsigned long currentMillis = millis();
            if (currentMillis - previousMillis >= interval)
            {
              previousMillis = currentMillis;
              s1.write(90 + (alpha*sin(frequency*counter*pi/180+0*beta + pi)+gamma)*180/pi);
              s2.write(90 + (alpha*sin(frequency*counter*pi/180+0.1*beta+pi/2 + pi)+gamma)*180/pi);
              s3.write(90 + (alpha*sin(frequency*counter*pi/180+0.2*beta + pi)+gamma)*180/pi);
              s4.write(90 + (alpha*sin(frequency*counter*pi/180+0.3*beta+pi/2 + pi)+gamma)*180/pi);
              s5.write(90 + (alpha*sin(frequency*counter*pi/180+0.4*beta+pi)+gamma)*180/pi);
              s6.write(90 - 13 + (alpha*sin(frequency*counter*pi/180+0.5*beta+pi/2+pi)+gamma)*180/pi);
              s7.write(90 - 7 + (alpha*sin(frequency*counter*pi/180+0.6*beta+pi)+gamma)*180/pi);
              counter += 1;
            }       
          }
        }
    flag =0;
  }
  else if(gait==1 && flag ==0)
  {
    flag = 1;
    Serial.println("The gait is:");
    Serial.println(gait);
    Serial.println("direction:");
    Serial.println(direc);
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

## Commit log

2017-12-12 Model and Simulation files added.
    [SS#504_Type1.step, SS#504_Type1.stl, SS#504_Type2.step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]
2018-02-13 3D printing files added
    [SS#504_Type1.step, SS#504_Type1.stl, SS#504_Type2.step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]
2018-02-13 Assembly of the Snake robot modeled in Fusion360
2018-02-13 3D printed parts added
    [Type1.step, Type1.stl, Type2.step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]
2018-03-14 CAD model added.
2018-03-14 Bot assembled.
2018-03-20 .stl files exported for blender modelling.
    [Module.stl, Motor.stl, Snake_head.stl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]
2018-03-20 .f3d file made to export .stl files for blender modelling.
    [NewDesignexport.f3d]
2018-03-30 Solidworks assembly file.
    [MainAssembly.SLDASM]
2018-03-30 Lowerbracket step file.
    [LowerBracket.step]
2018-03-30 Servo Metal horn
    [Metalhorn.step]
2018-03-30 Middle bracket of module
    [MiddleBracket.step]
2018-03-30 New head design supporting symmetry
    [Newhead.step]
2018-03-30 Servo motor without metal horn
    [Servo.step]
2018-03-30 Upper bracket of module.
    [UpperBracket.step]
2018-03-30 All the .SLDPRT files.
    [Head.SLDPRT, LowerBracket.SLDPRT, Metalhorn.SLDPRT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]
2018-03-30 All the sub-assemlies added.
    [Head_sub.SLDASM, Module.SLDASM, NewHead_sub.SLDASM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]
2018-03-31 New parts with .iges files
    [head_link.SLDPRT, link.SLDPRT, tail_link.SLDPRT]
2018-04-01 URDF package for ros/gazebo control
2018-04-01 Meshes added.
    [head_link.STL, link_0.STL, link_1.STL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]
2018-04-09 Cad model.
2018-04-10 Servo control.
2018-04-10 Wireless communication.
2018-04-17 Assembly of the bot.
    [NewDesignexport.f3d]
2018-04-17 New design assembly.
    [NewDesignexport.f3d]
2018-04-19 Bot's main assembly.
    [Head_sub.SLDASM, MainAssembly.SLDASM, Module.SLDASM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]
2018-04-19 Sub assembly of head.
    [Head_sub.SLDASM]
2018-04-19 Sub-assembly of tail.
    [Tail_sub.SLDASM]
2018-04-19 New design of head.
    [NewHead_sub.SLDASM]
2018-04-20 Sub-assemblies organized.
2018-05-26 .stl imports for vrep.
    [head_collider.stl, head_visible.stl, module_collider.stl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]
2018-05-27 .SLDPRT files from scratch.
    [head.SLDPRT, module.SLDPRT, tail.SLDPRT]
2018-06-01 Meshes (.dae)
    [Arboc.urdf, LowerBracket.step, Metalhorn.step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]
2018-06-01 Colliders altered.
    [model.sdf]
2018-06-30 3D printing details added.
2018-08-04 IMU with complimentary filter added
2018-08-05 Kalman filter and Results added
2018-08-09 Relative Angles for 2 imu with Kalman filter added
2018-08-15 Optimised code for 2 imu
2018-08-16 Heat sink specifications added
2018-08-18 Relative angle for 5 imus added
2018-08-19 Added few more .stl(S) and assembly file.
    [arboc.SLDASM, head.STL, module.STL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]
2018-08-19 Organized mechanical design files.
    [Module.stl, Motor.stl, NewDesignexport.f3d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]
2018-08-19 Power supply design added.
2018-08-19 Organized exports.
    [end.stl, headCollider.stl, headVisible.stl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]
2018-08-20 Corrected relative angle for subsequent links and parameters for kalman filter tuned
    [imu_multiplexer.ino]
